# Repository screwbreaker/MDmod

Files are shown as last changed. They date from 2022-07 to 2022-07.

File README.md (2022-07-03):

# MDmod
Yes, another Mega Drive switchless mod

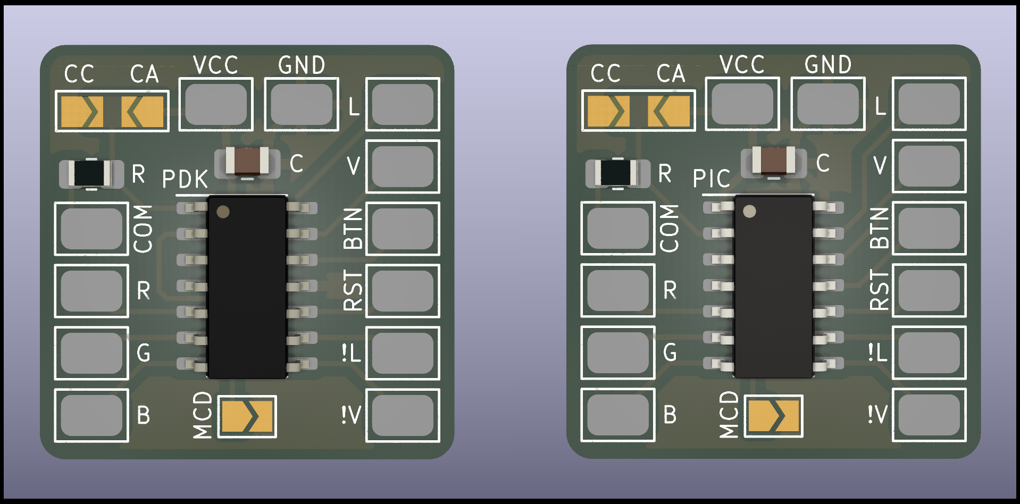
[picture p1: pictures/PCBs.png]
Board


### Summary
This is another version of the classic switchless MOD for Mega Drive/Genesis.
There are two version of this MOD.
One for Padauk microcontrollers. And one for the old PIC16F630.
For each micro there is a little PCB for help in the installation.

### History
Everything started because I got some Padauk microcontrollers, and I wanted to play with them.
I choose to implement the Mega Drive switchless mod, because it seem very appropriate, as a basic program for microcontrollers.

Unfortunately, I've never enought free time to work on this project.
When I finally managed to make it the padauk microcontrollers where out of stock.
They still cheap, but not easy to found now.
So, since SDCC also handle PIC microcontrollers, I thought it was nice to port the code for the old PIC16F630.

I also made some little PCB, to make the installation simpler.

That's it, that's why now there is another, or better, onother two switchless mod for Mega Drive.

### How it work
This version is very simple, it only allow to switch between the different regions, JP, USA, EU
There is no way to change only the region or only the video mode.

#### How to change region
Hold down the reset button.
After 2 seconds the region led start to blink fast.
The region shown change every second.
To confirm the region release the reset button.
The region led blink three times to confirm the selection.

#### Normal reset
Press the reset button for less than 2 seconds.

### BOM
Only few components, the micro, a decoupling capacitor, and a resistor for the LEDs.
- C: 100 nF 0805 capacitor
- R: 0805 resistor

### Warning
The PCB are not the same!
The two microcontroller have the same package but a different pinout.
So, each micro have his own board, don't mix them!

Do not close both CC and CA jumpers!

### LED
For the LED resistor I suggest a 10K resistor, but the value can be choose according to the particular LED used.
Just beware to do not exceed the maximum current for the microcontroller pin.
For more information, read the datasheet of the microcontroller.

The mode is writed for an RGB LED.
Other mods use two color led, this is not the case. You must use an RGB led.
Or, another way is to keep the original red led, and place antoher led near it.

The mod allow to use both common anode, or common cathode LEDs.
There is a little jumper on the board that allow to choose the LED type, the jumpers are marked as CA (common anode), CC (common cathode).
Do not close both jumpers!!!

The COM pad is the common, wich can be either VCC or GND, depens on which jumper is set.

### Mega CD mode
This mod expose two pins to control the switchless mod for the MCD.
The pins output are inverted respect the language and video pins, this is for compatibility with other mods.
Is possible to configure the mod to reset the console automatically after a region switch.
To enable the auto reset close the MCD jumper.

When the MCD mode is enabled the console is set in reset before set the language and video pins.
This is made to avoid unwanted access to the MCD bios meanwhile the eeprom is set to a different memory map.
However the microcontroller can't keep the Mega Drive in reset by holding the reset signal.
The reset signal is generated internally every time the button is pressed, the reset time is fixed and can't be extended.

### Reset issue
Sometime during a region change, an unwanted reset can happen.
The mod use a debounce to avoid this. But this is also dependant from the lenght of the wire from the reset button.
If you have such isse, increase the debounce delay in the firmware. Or, put a 100nF capacitor between the reset singal and GND (as close as possible to the micro).

### Padauk VS PIC
No differences, but the PIC also have an internal EPROM, so it can save the last mode used.
The padauk can't. The micro always start with the default region. The default region must be set in the firmware.

### Installation
Exactly like any other switchless MOD.
There are plenty guide online, they are well made, and cover all the Mega Drive/Genesis variants.
So, I'm not going to rewrite a guide.

Bot the boards are singe side, so the PCB back can be put in cotact with the Mega Drive board without issue.

### License
The PCBs are under the CERN OHL license.
The firmwares, under the GPL3.

This is an OPEN project.
So, like any other project like this, the hope is that others can improve it an reshare with the community.
Don't go out this basic guideline.

### Disclaimer
The hardware and the software are provided to you 'as is' and without any express or implied warranties whatsoever with respect to its functionality, operability or use, including, without limitation, any implied warranties of merchantability, fitness for a particular purpose or infringement. We expressly disclaim any liability whatsoever for any direct, indirect, consequential, incidental or special damages, including, without limitation, lost revenues, lost profits, losses resulting from business interruption or loss of data, regardless of the form of action or legal theory under which the liability may be asserted, even if advised of the possibility or likelihood of such damages.

### Thanks
- Thanks to the guys of the [Free PDK](https://free-pdk.github.io/) project. They are really smart and awesome!

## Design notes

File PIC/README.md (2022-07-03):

# MDmod PDK
Mega Drive switchless MOD for Padauk microcontroller

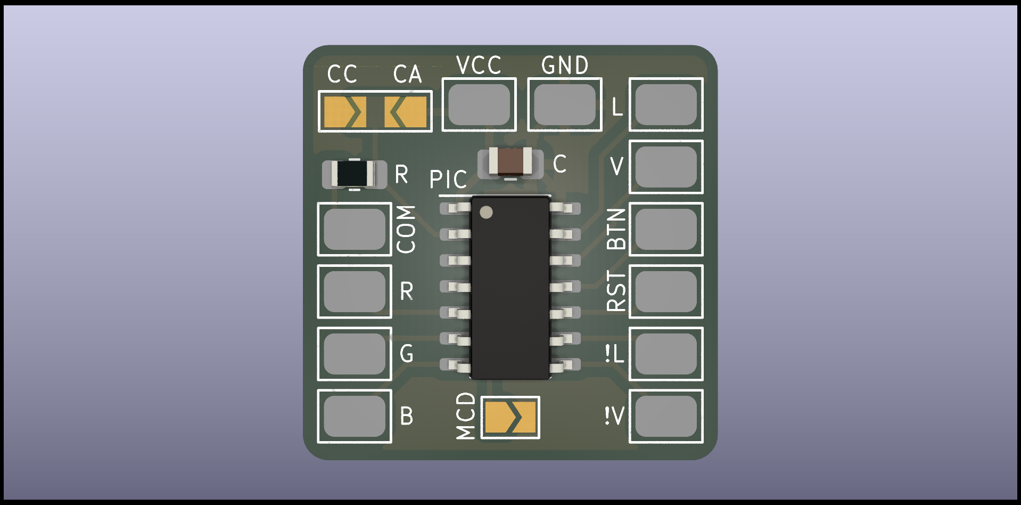
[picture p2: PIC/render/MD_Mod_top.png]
Board


### Summary
This mod is writted for the PIC16F630 microcontroller.
This mod is written with the SDCC. Maybe the SDCC is not the best for PIC, but it do the job very well.

### How to compile and program
This MOD must be compiled with [SDCC](http://sdcc.sourceforge.net/).
To program the micro I suggest the [Minipro/XGecu](http://www.xgecu.com/en/) programmer.
But i'm sure it can be programmed with the PICKit.

To compile use the "--use-non-free" parameter.
Or use the MAKEFILE in the firmware directory.

### License
The PCBs are under the CERN OHL license.
The firmwares, under the GPL3.

This is an OPEN project.
So, like any other project like this, the hope is that others can improve it an reshare with the community.
Don't go out this basic guideline.

### Disclaimer
The hardware and the software are provided to you 'as is' and without any express or implied warranties whatsoever with respect to its functionality, operability or use, including, without limitation, any implied warranties of merchantability, fitness for a particular purpose or infringement. We expressly disclaim any liability whatsoever for any direct, indirect, consequential, incidental or special damages, including, without limitation, lost revenues, lost profits, losses resulting from business interruption or loss of data, regardless of the form of action or legal theory under which the liability may be asserted, even if advised of the possibility or likelihood of such damages.

### Thanks
- The [SDCC](http://sdcc.sourceforge.net/) team.

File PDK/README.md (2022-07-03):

# MDmod PDK
Mega Drive switchless MOD for Padauk microcontroller

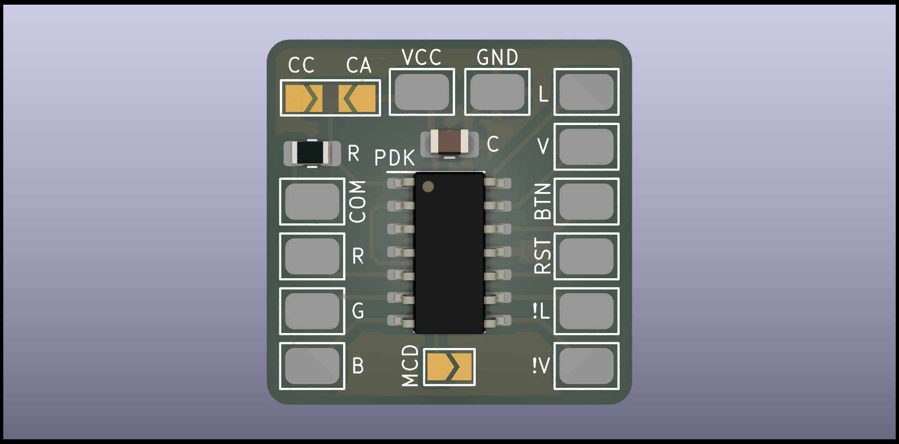
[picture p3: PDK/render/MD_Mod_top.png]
Board


### Summary
This mod is writted for the PFS173-S14 microcontroller.
But, it must be compatible with other Padauk microncontrollers of the same family. Included the OPT variants.
I've made some test with the PMS152, but not with the final version. Because I ran out of the micro.

If you test this MOD with other micro, please report the results.

### How to compile and program
This MOD must be compiled with [SDCC](http://sdcc.sourceforge.net/).
To program the micro I suggest the FreePDK programmer.
For any other information about the compiler and the programmer, please refer to the [FreePDK](https://free-pdk.github.io/) project.

### Default region
Since this microcontroller family don't have an internal EPROM, the micro always start with the default region.
Is possible to choose the default region by change it in the code before compiling.

### License
The PCBs are under the CERN OHL license.
The firmwares, under the GPL3.

This is an OPEN project.
So, like any other project like this, the hope is that others can improve it an reshare with the community.
Don't go out this basic guideline.

### Disclaimer
The hardware and the software are provided to you 'as is' and without any express or implied warranties whatsoever with respect to its functionality, operability or use, including, without limitation, any implied warranties of merchantability, fitness for a particular purpose or infringement. We expressly disclaim any liability whatsoever for any direct, indirect, consequential, incidental or special damages, including, without limitation, lost revenues, lost profits, losses resulting from business interruption or loss of data, regardless of the form of action or legal theory under which the liability may be asserted, even if advised of the possibility or likelihood of such damages.

### Thanks
- Thanks to the guys of the [Free PDK](https://free-pdk.github.io/) project. They are really smart and awesome!
- The [SDCC](http://sdcc.sourceforge.net/) team.

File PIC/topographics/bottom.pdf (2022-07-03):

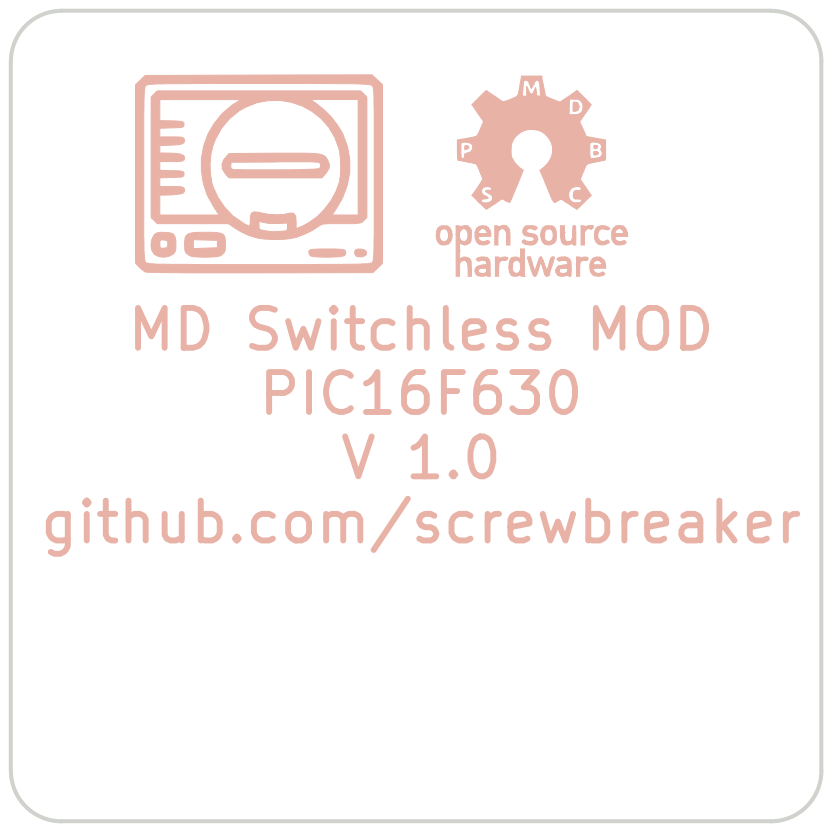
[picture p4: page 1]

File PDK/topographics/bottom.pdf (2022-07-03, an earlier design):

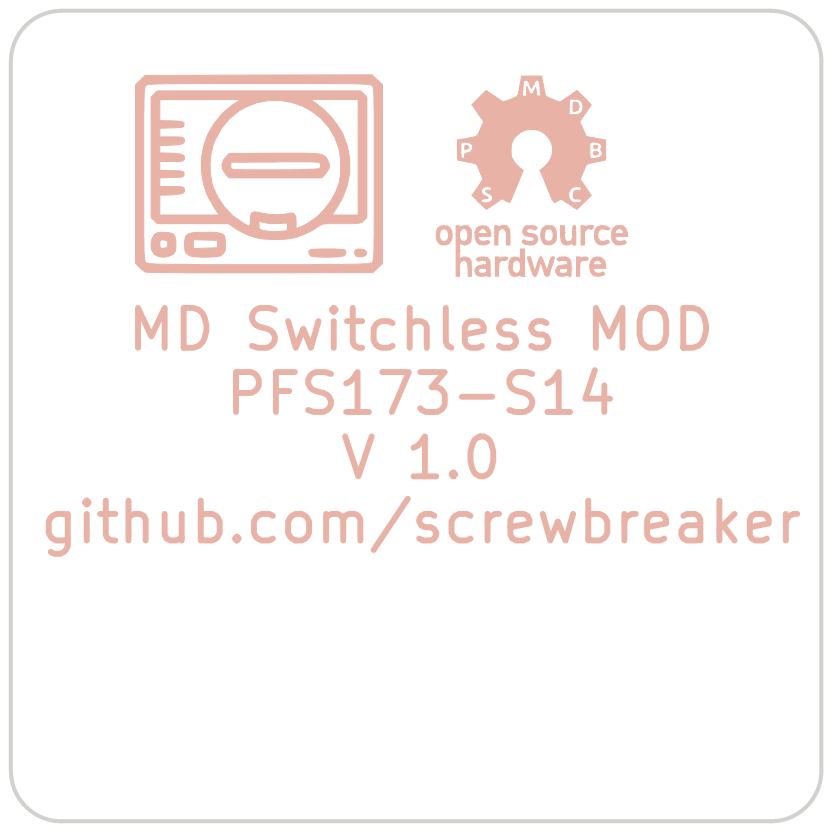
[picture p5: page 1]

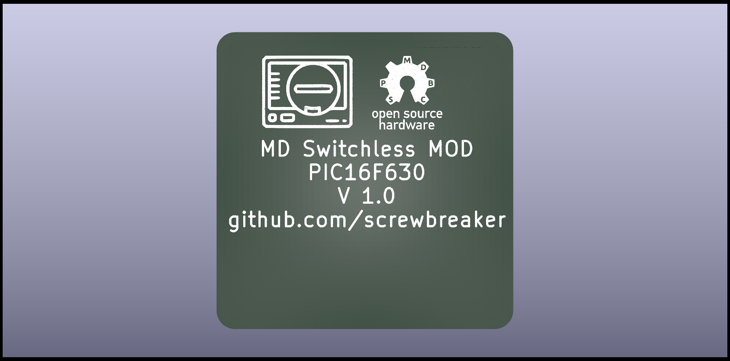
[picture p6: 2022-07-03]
PIC/render/MD_Mod_bottom.png

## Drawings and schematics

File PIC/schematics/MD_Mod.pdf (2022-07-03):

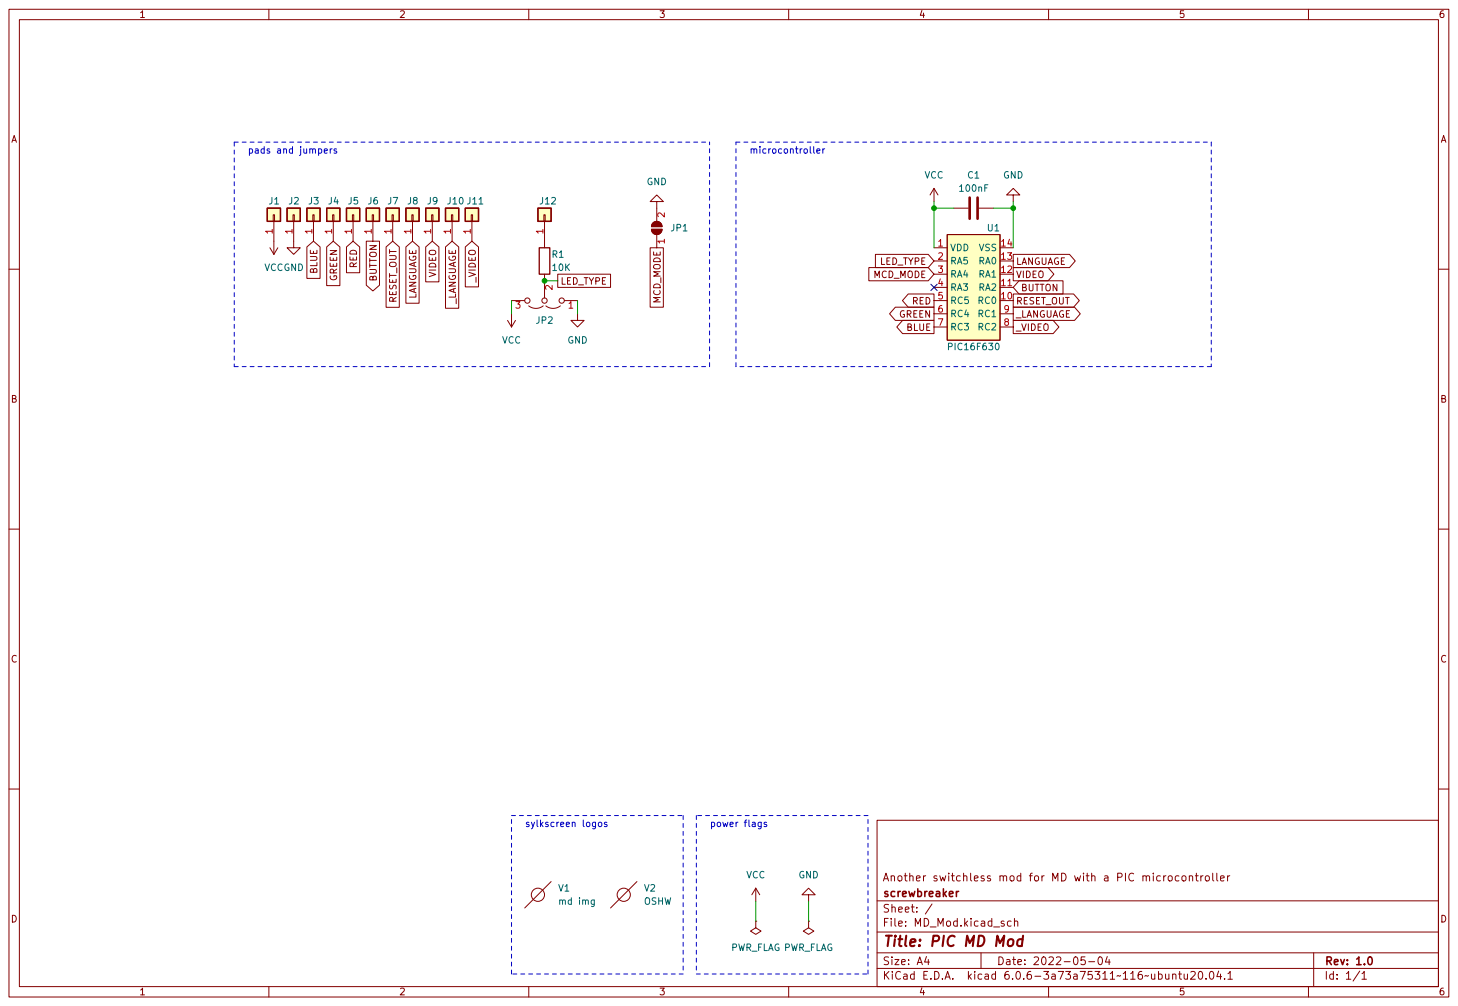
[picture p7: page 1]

File: MD_Mod.kicad_sch Sheet: / screwbreaker Another switchless mod for MD with a PIC microcontroller

Id: 1/1 Title: PIC MD Mod

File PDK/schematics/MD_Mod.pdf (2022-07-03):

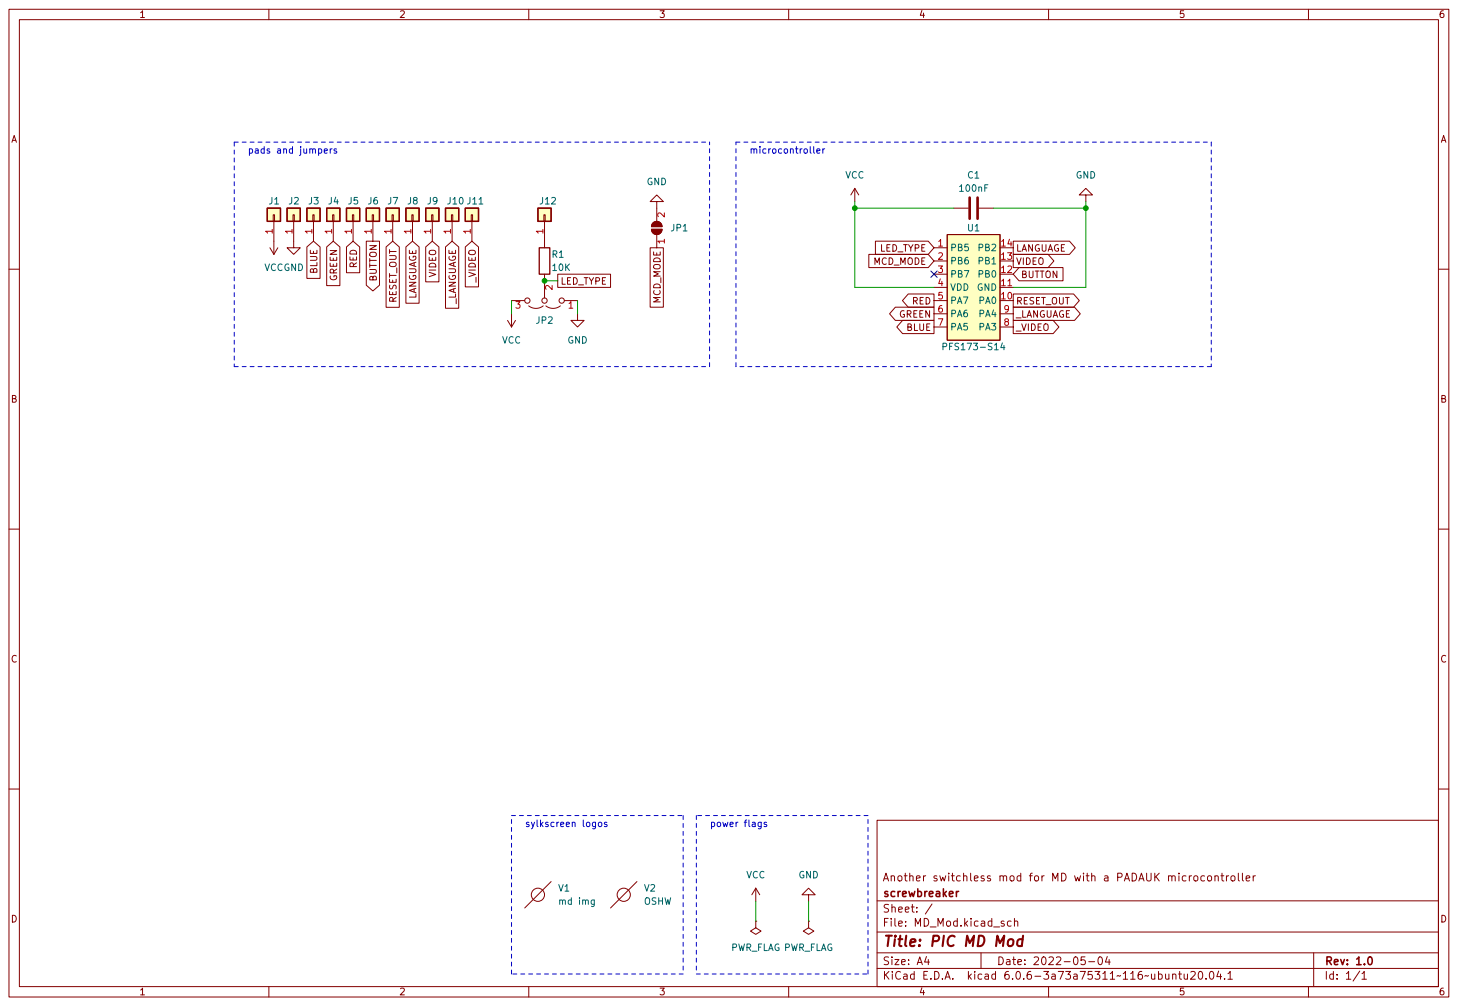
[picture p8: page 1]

File: MD_Mod.kicad_sch Sheet: / screwbreaker Another switchless mod for MD with a PADAUK microcontroller VCC

Id: 1/1 Title: PIC MD Mod

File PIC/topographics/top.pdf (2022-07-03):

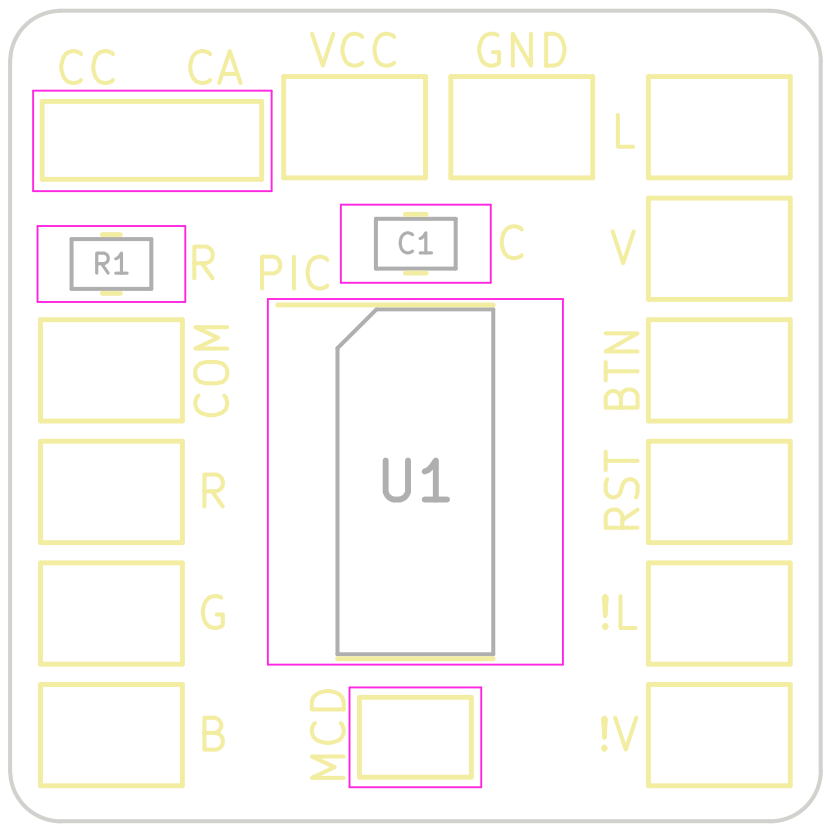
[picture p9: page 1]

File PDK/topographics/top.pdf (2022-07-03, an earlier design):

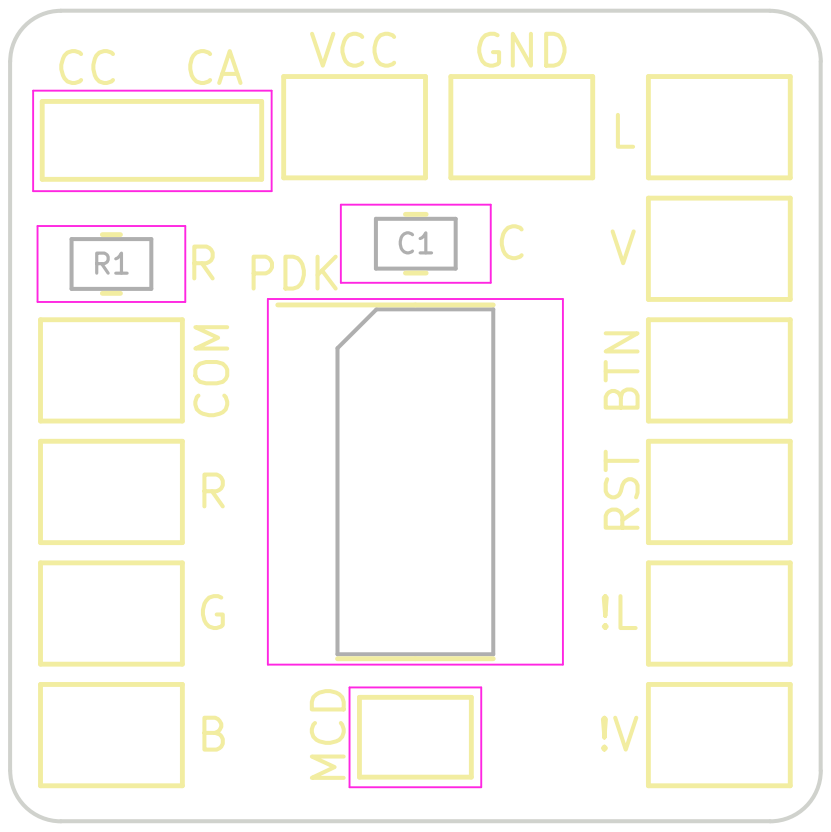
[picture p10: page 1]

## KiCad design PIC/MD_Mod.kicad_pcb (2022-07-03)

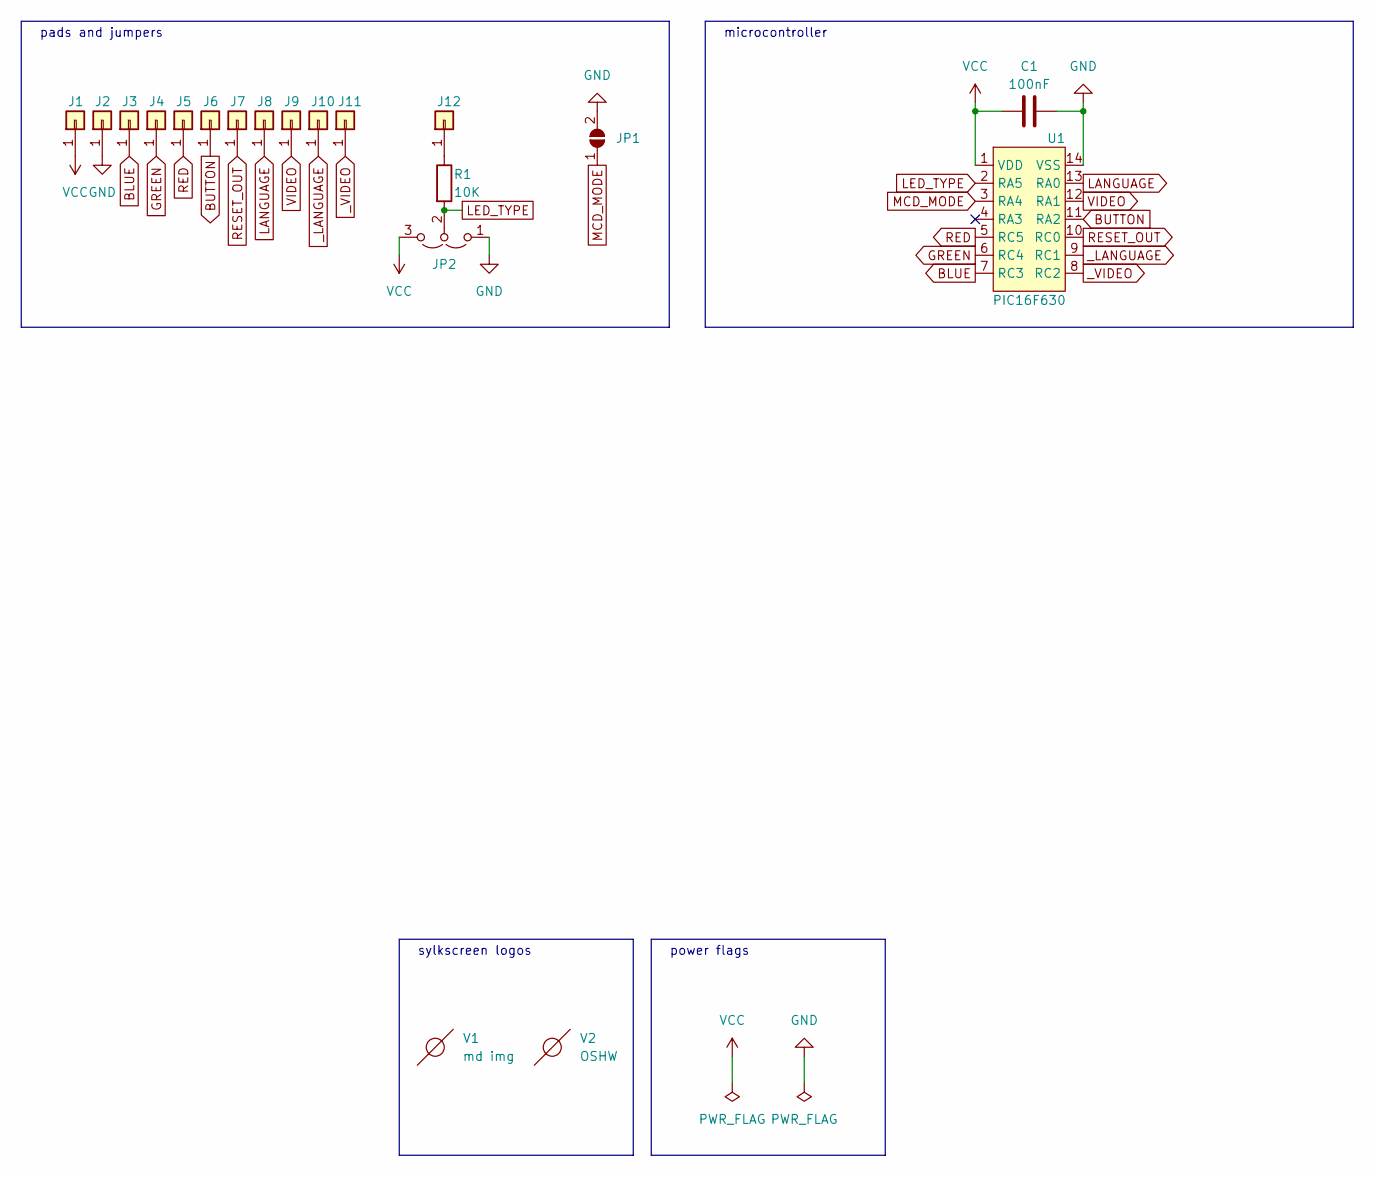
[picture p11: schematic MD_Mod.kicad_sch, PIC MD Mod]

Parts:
C1: 100nF; C_0805_2012Metric_Pad1.18x1.45mm_HandSolder; Manufacturer_Part_Number CC0805KRX7R9BB104
J1, J2, J3, J4, J5, J6, J7, J8, J9, J10, J11, J12: Conn_01x01; pad
JP1: SolderJumper_2_Open; SolderJumper-2_P1.3mm_Open_TrianglePad1.0x1.5mm
JP2: Jumper_3_Open; SolderJumper-3_P2.0mm_Open_TrianglePad1.0x1.5mm
R1: 10K; R_0805_2012Metric_Pad1.20x1.40mm_HandSolder; Manufacturer_Part_Number 0805S8J0103T5E
U1: PIC16F630; SOIC-14_3.9x8.7mm_P1.27mm; Manufacturer_Part_Number PIC16F630-I/SL
V1: md img; md_pic
V2: OSHW

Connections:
BLUE: J3.1, U1.7 (RC3)
BUTTON: J6.1, U1.11 (RA2)
GND: C1.2, J2.1, JP1.2 (B), JP2.1 (A), U1.14 (VSS)
GREEN: J4.1, U1.6 (RC4)
LANGUAGE: J8.1, U1.13 (RA0)
LED_TYPE: JP2.2 (C), R1.2, U1.2 (RA5)
MCD_MODE: JP1.1 (A), U1.3 (RA4)
unnamed: J12.1, R1.1
RED: J5.1, U1.5 (RC5)
RESET_OUT: J7.1, U1.10 (RC0)
VCC: C1.1, J1.1, JP2.3 (B), U1.1 (VDD)
VIDEO: J9.1, U1.12 (RA1)
_LANGUAGE: J10.1, U1.9 (RC1)
_VIDEO: J11.1, U1.8 (RC2)

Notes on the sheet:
microcontroller
pads and jumpers
sylkscreen logos
power flags

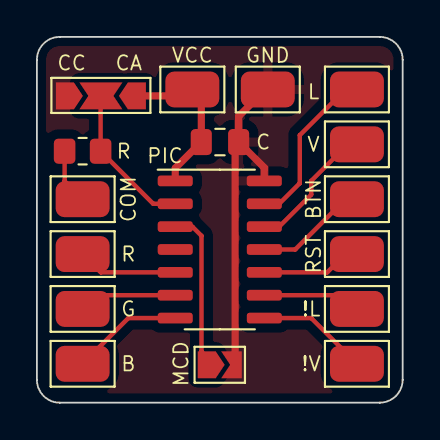
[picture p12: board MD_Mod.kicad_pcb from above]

Board: 2 copper layers, 20.3 x 20.3 mm, 19 parts (2 on the bottom side), 14 nets.

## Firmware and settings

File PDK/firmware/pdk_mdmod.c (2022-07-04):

/* Mega Drive switchless mod for Padauk ICs, to be compiled with SDCC.
 * 
 * made by screwbreaker
 * rev 1.0
 *
 * SYNOPSIS:
 * Yes, another switchless mod for Mega Drive
 * this version is very simple, it only allow to switch between the different regions, JP, USA, EU
 * there is no way to change only the region or the video mode
 *
 * HOW TO CHANGE REGION:
 * hold down the reset button
 * after 2 seconds the region led start to blink fast
 * the region shown change every second
 * to confirm the region release the reset button
 * the region led blink three times to confirm the selection
 *
 * NORMAL RESET:
 * press the reset button for less than 2 seconds
 *
 * MEGA CD MODE:
 * this mod expose two pins to control the switchless mod for the MCD
 * the pins output are inverted respect the language and video pins, this is for compatibility with other mods
 * is possible to configure the mod to reset the console automatically after a region switch
 * to enable the auto reset connect the MCD pin to ground
 *
 * when the MCD mode is enabled the console is set in reset before set the language and video pins
 * this is made to avoid unwanted access to the MCD bios meanwhile the eeprom is set to a different memory map
 * however the microcontroller can't keep the Mega Drive in reset by holding the reset signal
 * the reset signal is generated internally every time the button is pressed, the reset time is fixed and can't be extended
 * there are other reset singals inside the mega drive, this is used by games or expansions to control the reset signal
 * this mod expose a second reset pin, to allow to control other reset signal inside the console
 * this pin is an open drain, is intended to be put in parallel to the other devices
 * this feature is for future use or test only, do not use it at the moment
 *
 * LED DRIVE TYPE:
 * is possible to choose either a common anode or a common cathode LED
 * one pin is used to choose the led type, the pin is tied to VCC with the internal pull-up
 * if not connected the default choose is for a commmon anode led
 *
 * check the datasheet for the microcontroller to check the maximum current to drive the LEDS
 * LEDs generally needs a very small current, expecially if used as indicator like in this case
 * my suggestion is to drive them with the smallest current as possible, no more than 5ma
 */

/* includes */
#include "pdk.h"
#include "utils.h"

/* global defines */
#define DEFAULT_REGION EU	// This is the default region used on the first boot

// pin settings
#define RED		PA,7	// red LED
#define GREEN		PA,6	// green LED
#define BLUE		PA,5	// blue LED

#define VIDEO		PB,1	// video (50/60Hz)
#define LANGUAGE	PB,2	// language (ENG/JAP)
#define _VIDEO		PA,3	// inverted video (For Mega CD)
#define _LANGUAGE	PA,4	// inverted language (For Mega CD)
#define RESET		PA,0	// reset output
#define BUTTON		PB,0	// reset button in
#define MCD		PB,6	// if low enable the Mega CD mode, reset the console after a region change
#define LED_TYPE	PB,5	// HIGH = common anode, LOW = common cathode

/* do not modify anything under this line */

#define ledOn(led)	bools.led_type ? (clearBit(led)) : (setBit(led))
#define ledOff(led)	bools.led_type ? (setBit(led)) : (clearBit(led))

#define isBtnPressed	isPinLow
#define reset()		bools.reset = true; \
			delay = RESET_DELAY
#define next_region()	region = ((region + 1) % REGIONS)

#define RESET_DELAY	33	// about 270ms
#define DEBOUNCE_DELAY	5	// about 40ms
#define CHANGE_TIME	200	// about 1.6 sec with 8ms tick
#define LED_FAST_DELAY	16	// about 130ms with 8ms tick
#define LED_SLOW_DELAY	33	// about 270ms with 8ms tick
#define SHOW_TURNS	8	// about 1s
#define CONFIRM_TURNS	5	// 3 slow blinks

#define ALL_OFF REGIONS

/* global typedefs and structures */
typedef union {
	struct {
		unsigned tick		: 1;
		unsigned btn_event	: 1;
		unsigned show_regions	: 1;
		unsigned confirm_region	: 1;
		unsigned reset		: 1;
		unsigned led_state	: 1;
		unsigned mcd		: 1;
		unsigned led_type	: 1;
	};

	struct {
		unsigned BOOLS		: 8;
	};
} __Bools_t;

typedef enum {
	JP = 0x00,
	EU,
	US,
	REGIONS
} region_t;

/* functions prototypes */
void set_led(region_t region);
void set_region(void);
void set_mcd(void);

/* global variables */
volatile region_t region = DEFAULT_REGION;
volatile __Bools_t bools;
volatile uint8_t turns = 0;
volatile uint8_t delay = 0;
volatile uint8_t debounce_delay = 0;
volatile uint32_t btn_counter = 0;

// interrupt handler (kept as simple/minimalistic as possible)
void interrupt(void) __interrupt(0) {
	// monitor the MD reset button
	if (INTRQ & INTRQ_PB0) {
		if (!debounce_delay) {
			debounce_delay = DEBOUNCE_DELAY;
			bools.btn_event = true;
			INTRQ &= ~INTRQ_PB0;
		}
	}

	// when T16 'ticks'
	if (INTRQ & INTRQ_T16) {
		bools.tick = true;
		INTRQ &= ~INTRQ_T16;
	}
}

unsigned char _sdcc_external_startup(void) {
	// setup 8MHz sysclock and let easypdk programmer do the calibration (after writing)
	EASY_PDK_INIT_SYSCLOCK_8MHZ();		//use 8MHz sysclock
	EASY_PDK_CALIBRATE_IHRC(8000000,5000);	//tune SYSCLK to 8MHz @ 5.000V
	EASY_PDK_CALIBRATE_BG();
	EASY_PDK_FUSE(FUSE_BOOTUP_FAST | FUSE_SECURITY_OFF);
	return 0;
}

// timers and pin setup
void setup() {
	setPinOutput(RED);
	setPinOutput(GREEN);
	setPinOutput(BLUE);

	setPinOutput(VIDEO);
	setPinOutput(LANGUAGE);
	setPinOutput(_VIDEO);
	setPinOutput(_LANGUAGE);

	setPinOutput(RESET);
	setPin(RESET);

	enableDigitalInput(LED_TYPE);
	setPinPullup(LED_TYPE);

	enableDigitalInput(MCD);
	setPinPullup(MCD);

	enableDigitalInput(BUTTON);
	setPinPullup(BUTTON);

	// enable T16 timer to generate an interrupt about every 8 milliseconds
	T16M = T16_CLK_IHRC | T16_CLK_DIV64 | T16_INTSRC_10BIT;	// Use IHRC clock source (16 MHz), /64, Interrupt on (rising) Bit 10
	INTEN = INTEN_T16| INTEN_PB0;
	INTEGS = INTEGS_T16_RISING | INTEGS_PB0_BOTH;

	// enable interrupts
	INTRQ = 0;
	__engint();	// enable global interrupts
} // setup()
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
